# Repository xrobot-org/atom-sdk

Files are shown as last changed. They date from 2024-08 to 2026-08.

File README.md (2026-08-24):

# ATOM-IMU 模块 V5.3

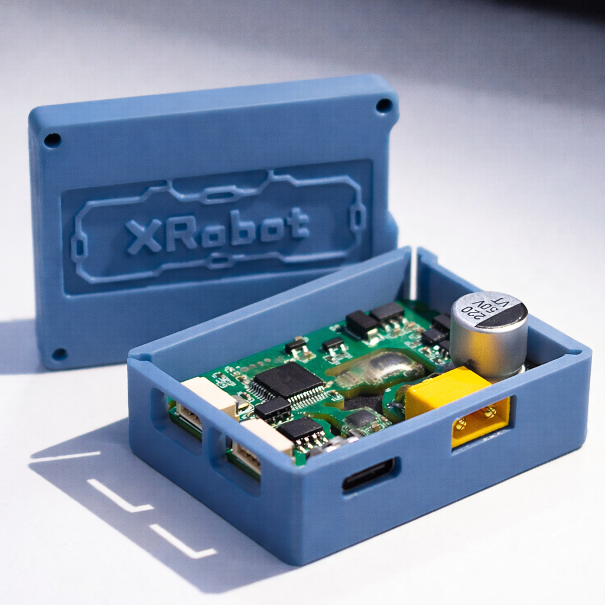
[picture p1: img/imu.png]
imu


## **参数**

- **输出频率**：2-2000Hz
- **支持电压**：5V/24V
- **接口**：USB / UART / CAN
- **支持数据类型**：加速度计 (ACC) / 陀螺仪 (GYRO) / 欧拉角 (EULR) / 四元数 (QUAT)
- **UART 波特率**：2M (数据)
- **CAN 波特率**：1M
- **陀螺仪**：最大量程 ±2000DPS
- **加速度计**：最大量程 ±24G

usb接口会在电脑上枚举出两个CDC虚拟串口，分别为命令行与数据输出。虚拟串口输出的IMU数据与硬件串口格式相同。

不建议使用USB转TTL连接硬件串口。硬件串口波特率较高，需要选择支持此波特率（2M）的USB转TTL模块。模块自带的USB接口延迟更低，速度更快。

## **Yaw轴零漂测试**

零偏通常在10°/h以下，校准环境较好时可达3°/h以下。

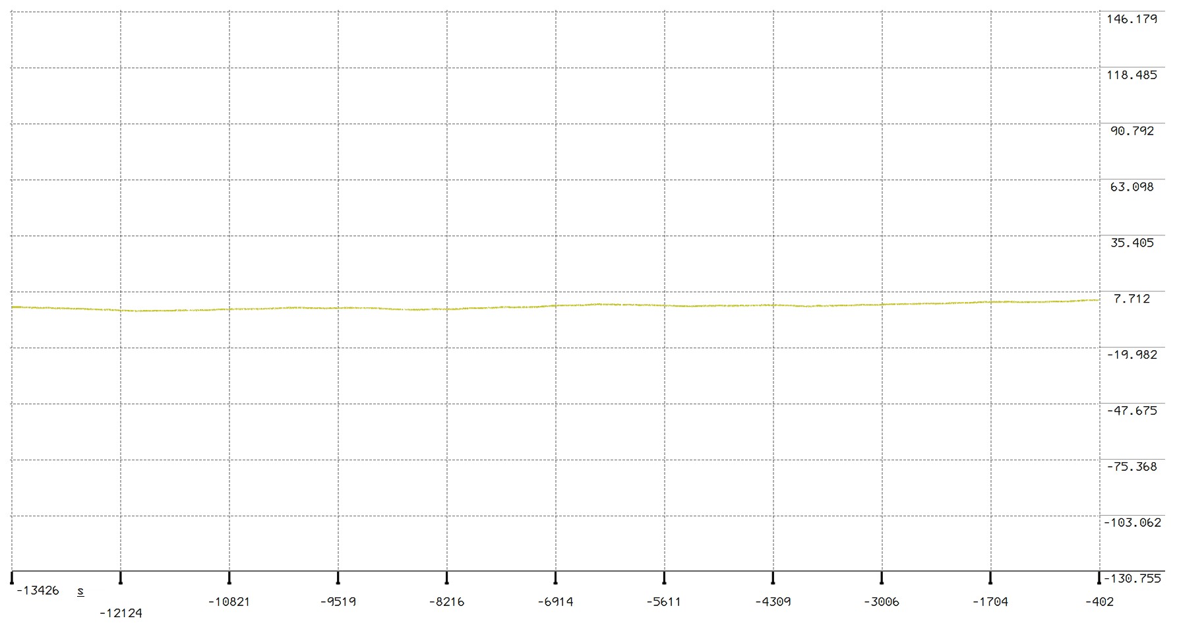
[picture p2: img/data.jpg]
data


## **连接方式**

- **USB**：`UART1(数据输出) UART2(命令行)`
- **UART GH1.25 4P**：
  - `1: SYNC / FSYNC`（可配置为输入或输出）
  - `2: TX`
  - `3: GND`
  - `4: +5V_IN`
- **CAN GH1.25 4P**：
  - `1: CANL`
  - `2: CANH`
  - `3: GND`
  - `4: +5V_IN`
- **XT30 供电**：`24V_IN`

## **示例代码**

```shell
├── linux_uart_example      `Linux UART 解析示例`
├── ros_imu_publisher       `ROS IMU 发布节点`
├── ros_imu_subscriber      `ROS IMU 订阅节点`
├── ros_rviz_example.rviz   `ROS RViz 可视化`
└── stm32_can_example       `STM32 CAN 解析示例（5.3不支持CANFD）`
```

### **Linux UART 示例**

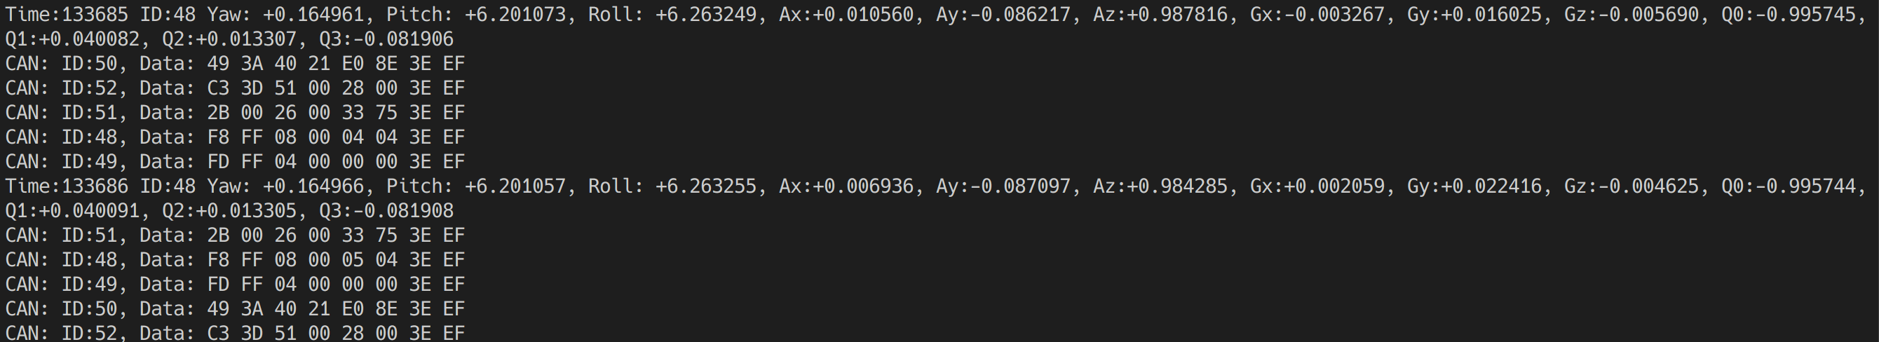
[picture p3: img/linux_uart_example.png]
linux_uart_example


编译并运行示例：

```shell
gcc main.c -o main
./main
```

### **ROS 示例**

VERSION=`rolling`

#### 发布

```shell
colcon build
source install/setup.zsh
ros2 run imu_publisher node_imu
```

#### 订阅

```shell
colcon build
source install/setup.zsh
ros2 run imu_subscriber node_imu
```

### **RViz 可视化**

使用 `ros_rviz_example.rviz` 在 RViz2 中打开。

### **STM32 CAN 示例**

```shell
make
```

## **终端交互**

使用 `picocom`、`putty`、`MobaXTerm` 等工具进行交互，连接USB枚举出的第二个串口设备即可。
示例操作：

```shell
linux@XRobot:~$ ls /dev/ttyACM*
/dev/ttyACM0  /dev/ttyACM1

linux@XRobot:~$ picocom /dev/ttyACM1
```

回车后示例输出：

```shell
XRobot:/$
```

## **IMU 设置**

```shell
# 输入set_imu命令并回车
XRobot:/$ set_imu
# 这一行显示IMU CAN输出的状态，CAN/UART输出同时只能有一个开启
can output disabled.
# 这一行显示IMU 串口输出的状态
uart output enabled.
# 这一行表示帧同步信号FSYNC的模式：
#   0=不启用
#   1=检测上升沿
#   2=检测下降沿
#   3=同时检测上升沿/下降沿
#   4=输出FSYNC时钟（UART口 SYNC/FSYNC 引脚输出）
# 第二个数字代表最近一次FSYNC事件的时间（微秒）
# 第三个数字代表最近一次IMU数据时间戳（微秒）
FSYNC:4 6685000 6690413
# 当 fsync=4（输出）时，会额外显示输出分频参数（Div）
Div:10
# 这一行显示两次反馈数据的时间间隔，单位500us
feedback delay:1
# 这一行显示IMU数据帧的ID
id:48

Usage:
        set_delay  [time]  设置发送延时 1=500us
        set_div    [div]   设置clk_out(FSYNC)分频
        set_can_id [id]    设置can id
        just_float         设置vofa+ just_float输出
        # accl/gyro/quat/eulr只对can模式发送有效
        enable/disable     [accl/gyro/quat/eulr/can/uart]
        fsync              [0: disable 1: rise 2: fall 3: both 4: output]           设置fsync模式
```

## **校准（Calibration）**

完整校准过程约需 **20 分钟**，过程中需要保证 IMU 稳定，每次更改IMU方向后需要等待1分钟以上来使角度稳定。校准的每一步都无顺序要求，可以多次尝试。

```shell
# 上电后等待十分钟，IMU预热
XRobot:/$ imu1 show 600000 1000
# IMU平放，LOGO面朝上
XRobot:/$ imu1 cali
...
# 校准误差绝对值在0.00003以下视为校准成功，理想情况下应当小于0.000015
Calibration error -0.000013
Calibration data saved.
# 更改方向，USB接口面朝下
XRobot:/$ imu1 cali
...
# 侧放IMU，使GH1.25接口朝上
XRobot:/$ imu1 cali
...
# 再次将IMU平放，LOGO面朝上
XRobot:/$ imu2 cali
...
# 搜索得到当地的经纬度，可在谷歌地图中直接右键复制。例如格拉斯哥的经纬度为：55.87241068336635 -4.290120205979219
XRobot:/$ ahrs set_location 55.87 -4.29
Done.
# 校准完成
```

## **测量零漂**

仅作参考，以实际情况为准

```shell
XRobot:/$ ahrs test
Please keep the device steady, start measurement
Please wait
Zero offset:-0.035189°/min
```

## **VOFA+ 可视化数据**

请添加以下自定义命令，使用VOFA+可视化数据。
数据分别为：`w x y z pitch roll yaw`

```shell
ahrs print_quat 1000000 10\r\n
```

## **调整恒温温度**

```shell
# 设置恒温温度  
# 两个IMU温度同步，修改一个即可
XRobot:/$ imu1 set_temp 45

# 重新上电并校准
```

## **FSYNC 输入模式（fsync=1/2/3）**

根据触发模式的不同，`Data.sync`会记录输入信号的边沿触发时间。

## **FSYNC 输出模式（fsync=4）**

当 `fsync` 设置为 `4` 时，模块会在 **UART GH1.25 的 1 号脚（SYNC/FSYNC）** 输出方波时钟，用于外部同步。

- `Data.sync` 字段记录**最近一次 FSYNC 输出上升沿所对应的 IMU 采样结束/数据就绪时间戳**（微秒）
- `Data.sync` 仅在 FSYNC 上升沿发生时更新，其余数据帧会保持为“最近一次上升沿对应的 `sync` 值”
- FSYNC 输出上升沿相对 `Data.sync` 的延迟约为 **8.5µs**（典型值）
- 输出分频由 `set_div [div]` 控制（仅 `fsync=4` 时生效）
- `set_delay [delay]` 为发送/反馈节拍，单位 500µs（`delay=1` 即 500µs）
- 在当前固件中，内部数字滤波带来的群延迟典型值约为 **1.5ms**

输出周期计算：
- **翻转间隔**：`500µs × delay × div`
- **方波周期**：`500µs × delay × div × 2`

示例：`delay=2`（1ms），`div=5`  
方波周期 = `500µs × 2 × 5 × 2 = 10ms`，即 **100Hz**。

---

## **路径延迟**

在当前配置下，IMU 采样周期约为 **500µs**。  
IMU 采样结束到 FSYNC 输出**上升沿**需要约 **8.5µs**。

例如使用 FSYNC 触发相机采集时：

- IMU 采样时间中点约为：`Data.sync - 250µs`
- 相机采集时间中点约为：`Data.sync + 8.5µs + 相机触发上升沿延迟 + 曝光时间/2`

因此可结合 `Data.sync` 与 `Data.time`，在 IMU 数据流中选择**距离相机采集时间中点最近**的 IMU 数据帧。

此外，更改 `set_delay [delay]` 或 `set_div [div]` 均会在**当前周期结束后**生效，运行时更改不会导致相位偏移。  
因此可通过调整 `div`，并同时监控**相机帧时间差**与**IMU 数据时间差**（相对上一帧的 Δt）来对齐相机与 IMU 数据。

sync

## 3D 模型

[Top Model](./3D/Top.step)

[Bottom Model](./3D/Bottom.step)

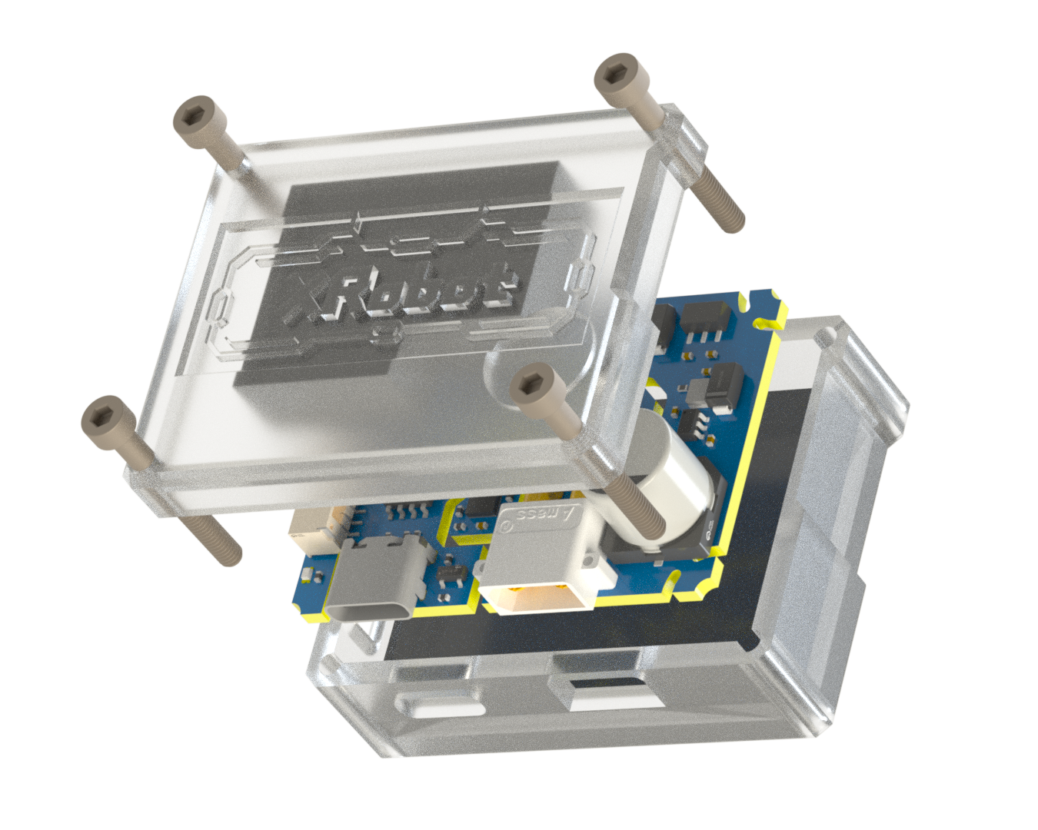
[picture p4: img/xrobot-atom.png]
View


## **传输协议**

### **UART 协议**

- 数据帧包括：前缀，微秒时间戳（time），同步时间戳（sync），四元数，角速度，加速度，欧拉角，CRC8 校验。

```c++
typedef struct __attribute__((packed)) {
  float x;
  float y;
  float z;
} Vector3;

typedef struct __attribute__((packed)) {
  float q0;
  float q1;
  float q2;
  float q3;
} Quaternion;

typedef struct __attribute__((packed)) {
  float yaw;
  float pit;
  float rol;
} EulerAngles;

typedef struct __attribute__((packed))
{
  uint8_t prefix;
  uint64_t time : 40;
  uint64_t sync : 40;
  Quaternion quat_;
  Vector3 gyro_;
  Vector3 accl_;
  EulerAngles eulr_;
  uint8_t crc8;
} Data;
```

### **CAN 协议**

```c++
#define ENCODER_21_MAX_INT ((1u << 21) - 1)
#define CAN_PACK_ID_ACCL 0
#define CAN_PACK_ID_GYRO 1
#define CAN_PACK_ID_EULR 3
#define CAN_PACK_ID_QUAT 4

typedef union {
  struct __attribute__((packed)) {
    int32_t data1 : 21;
    int32_t data2 : 21;
    int32_t data3 : 21;
    int32_t res : 1;
  };
  struct __attribute__((packed)) {
    uint32_t data1_unsigned : 21;
    uint32_t data2_unsigned : 21;
    uint32_t data3_unsigned : 21;
    uint32_t res_unsigned : 1;
  };
  uint8_t raw[8];
} CanData3;

typedef struct __attribute__((packed)) {
  union {
    int16_t data[4];
    uint16_t data_unsigned[4];
  };
} CanData4;

typedef struct {
  struct {
    float x, y, z;
  } accl;
  struct {
    float x, y, z;
  } gyro;
  struct {
    float pitch, roll, yaw;
  } eulr;
  struct {
    float w, x, y, z;
  } quat;
  uint64_t timestamp;
  uint64_t sync_time;
} ImuData;

ImuData imu_data;

static float DecodeFloat21(uint32_t encoded, float min, float max) {
  float norm =
      (float)(encoded & ENCODER_21_MAX_INT) / (float)ENCODER_21_MAX_INT;
  return min + norm * (max - min);
}

static float DecodeInt16Normalized(int16_t value) {
  return (float)value / (float)INT16_MAX;
}

static void ProcessClassicCanPacket(uint32_t id, uint8_t *data) {
  uint32_t packet_type = id - IMU_DEVICE_ID;

  switch (packet_type) {
  case CAN_PACK_ID_ACCL: {
    /* Accelerometer data: ±24g range */
    CanData3 *can_data = (CanData3 *)data;
    imu_data.accl.x = DecodeFloat21(can_data->data1_unsigned, -24.0f, 24.0f);
    imu_data.accl.y = DecodeFloat21(can_data->data2_unsigned, -24.0f, 24.0f);
    imu_data.accl.z = DecodeFloat21(can_data->data3_unsigned, -24.0f, 24.0f);
    break;
  }

  case CAN_PACK_ID_GYRO: {
    /* Gyroscope data: ±2000 deg/s converted to rad/s */
    CanData3 *can_data = (CanData3 *)data;
    float min_gyro = -2000.0f * M_PI / 180.0f;
    float max_gyro = 2000.0f * M_PI / 180.0f;
    imu_data.gyro.x =
        DecodeFloat21(can_data->data1_unsigned, min_gyro, max_gyro);
    imu_data.gyro.y =
        DecodeFloat21(can_data->data2_unsigned, min_gyro, max_gyro);
    imu_data.gyro.z =
        DecodeFloat21(can_data->data3_unsigned, min_gyro, max_gyro);
    break;
  }

  case CAN_PACK_ID_EULR: {
    /* Euler angles: ±π rad */
    CanData3 *can_data = (CanData3 *)data;
    imu_data.eulr.pitch = DecodeFloat21(can_data->data1_unsigned, -M_PI, M_PI);
    imu_data.eulr.roll = DecodeFloat21(can_data->data2_unsigned, -M_PI, M_PI);
    imu_data.eulr.yaw = DecodeFloat21(can_data->data3_unsigned, -M_PI, M_PI);
    break;
  }

  case CAN_PACK_ID_QUAT: {
    /* Quaternion data: normalized int16 */
    CanData4 *can_data = (CanData4 *)data;
    imu_data.quat.w = DecodeInt16Normalized(can_data->data[0]);
    imu_data.quat.x = DecodeInt16Normalized(can_data->data[1]);
    imu_data.quat.y = DecodeInt16Normalized(can_data->data[2]);
    imu_data.quat.z = DecodeInt16Normalized(can_data->data[3]);
    break;
  }

  default:
    /* Unknown packet type */
    break;
  }
}
```

## **固件说明**

- `bootloader.bin`
  - Bootloader 镜像，仅用于写入 Bootloader
- `firmware/` 目录下的 `firmware_*.elf`
  - 应用固件，用于通过 WebDFU 下载到设备
  - 例如：
    - `firmware_25-12-21.elf`
    - `firmware_25-12-28.elf`

请勿将 `bootloader.bin` 作为应用固件下载，否则设备将停留在 Bootloader / DFU 模式。

## **首次烧录流程**

用于首次装配后的上电，或设备中尚无应用固件时。

1. 写入 Bootloader。
   - 使用 1.25 4P 探针连接 SWD 接口，烧录 [bootloader.bin](./firmware/bootloader.bin)
   - 或按硬件流程短接 `boot`（`R66`），进入 DFU 下载模式后烧录 Bootloader
2. 重启设备。
3. 若设备中尚无应用固件，重启后会自动进入 Bootloader。
4. 重新插拔 USB。
5. 打开此网站：[ATOM-IMU 固件更新](https://jiu-xiao.github.io/webdfu/dfu-util/)
6. 选择 `firmware/` 目录下的 `firmware_*.elf` 作为应用固件。
7. 按页面提示完成下载。
8. 再次重新插拔 USB。
9. 命令串口回车后出现 `XRobot:/$`，表示应用固件已启动。

## **应用固件更新**

用于设备已具备可运行的应用固件，需要升级版本时。

1. 准备新的 `firmware_*.elf`。
2. 通过命令串口执行：

   ```sh
   power bl
   ```

3. 设备进入 Bootloader 后，重新插拔 USB。
4. 打开此网站：[ATOM-IMU 固件更新](https://jiu-xiao.github.io/webdfu/dfu-util/)
5. 选择新的 `firmware_*.elf`，按页面提示完成更新。
6. 再次重新插拔 USB。
7. 命令串口回车后出现 `XRobot:/$`，表示更新完成。

若当前应用固件无法进入命令串口，可按“首次烧录流程”重新进入 Bootloader，再重新下载应用固件。

## **焊接建议**

- `BMI088`、`BMI270` 可先对引脚和焊盘植锡，再整体吹焊；可按类似 `BGA` 的回流焊法操作。
- 若多次重焊 `BMI088`、`BMI270` 后仍无法恢复，再排查 `STM32` 侧焊接、`SPI`、`CS`、中断、供电或芯片本体损坏。

## **常见问题与故障处理**

下面的时间戳、文件行号会随固件版本变化，排查时优先看**日志关键字**。

| 现象 / 日志特征 | 最可能原因 | 处理建议 |
| --- | --- | --- |
| 上电后始终停在 Bootloader，或设备行为一直像 DFU 更新设备 | 将 `bootloader.bin` 当成了应用固件烧录 | `bootloader.bin` 仅用于 Bootloader，本体固件请使用 `firmware/` 目录中的 app 固件；重新进入 Bootloader 后，按上面的固件更新流程重新烧录 app |
| 烧录 `bootloader.bin` 后，或短接 `boot`（`R66`）后，USB 仍不枚举 | 通常不是应用固件问题，应优先视为 `USB` 硬件链路异常 | 检查 `USB` 连接器、`USB` 相关电阻、`STM32 USB` 引脚、`USB` 相关晶振及其周边焊点 |
| 两个 COM 口都能枚举，但 IMU 没有正常输出 / 陀螺仪不出数据 | 通常不是 USB 枚举问题，而是 IMU 相关焊接问题 | 优先检查 `BMI088`、`BMI270` 及其周边焊接；如果串口和 CLI 正常，但传感器数据异常，先不要把问题归到上位机 |
| `W [200933] (./Modules/BMI270/BMI270.hpp:398) IMU2:Writesingle timeout reg=0x7E data=0xB6` | `BMI270` 寄存器写入后读回不一致，常见原因为 SPI 虚焊、连焊或芯片本体异常 | 重点检查 `BMI270` 供电、SPI 焊点和芯片姿态；建议补锡后热风重焊，必要时更换芯片 |
| `W [201044] (./Modules/BMI270/BMI270.hpp:341) IMU2:bad CHIP ID` | `BMI270` 软复位后再次读取 `CHIP_ID` 失败，常见原因为 SPI 虚焊 | 优先按 `BMI270` SPI 焊接问题处理；先查焊点、再查芯片 |
| `E [112547] (./Modules/BMI088/BMI088.hpp:260) IMU1: Init failed.` | `BMI088` 初始化失败。源码里对应的是加速度计或陀螺仪 `CHIP_ID` 读取不正确，常见原因为 SPI 虚焊，也可能是供电 / 片选异常 | 重点检查 `BMI088` 本体焊接、SPI 引脚、CS 连接与供电连通；建议先植锡再回流重焊 |
| `W [28734] (./Modules/BMI088/BMI088.hpp:368) IMU1 wait timeout.` | `BMI088` 初始化后 50ms 内未等到新数据中断，常见原因为中断引脚虚焊 | 这类问题常见于 **能读到器件但等不到中断**；优先检查 `BMI088` 中断脚及其到 MCU 的走线/焊点 |
| `BMI088`、`BMI270` 多次重焊后仍无法通信，或 IMU 仍无法识别 | 除传感器本体外，也可能是 `STM32` 侧虚焊 | 检查 `STM32` 与 IMU 相连的 `SPI`、`CS`、中断、供电等相关焊点 |
| 加热电阻不工作，或温度长时间无法上升 | 可能是加热回路异常，也可能是 `STM32 PWM` 引脚虚焊 | 检查加热电阻、供电回路及 `STM32 PWM` 输出相关焊点 |

附上：[XRobot 开源 IMU 手动焊接烈士榜](https://github.com/xrobot-org/atom-sdk/blob/master/XRobot%20%E5%BC%80%E6%BA%90%20IMU%20%E6%89%8B%E5%8A%A8%E7%84%8A%E6%8E%A5%E7%83%88%E5%A3%AB%E6%A6%9C.pdf) 包含最近交流群内的焊接成功/失败记录

## **相关资源**

- [Bilibili 视频演示](https://www.bilibili.com/video/BV1iespeLE5S/?share_source=copy_web)

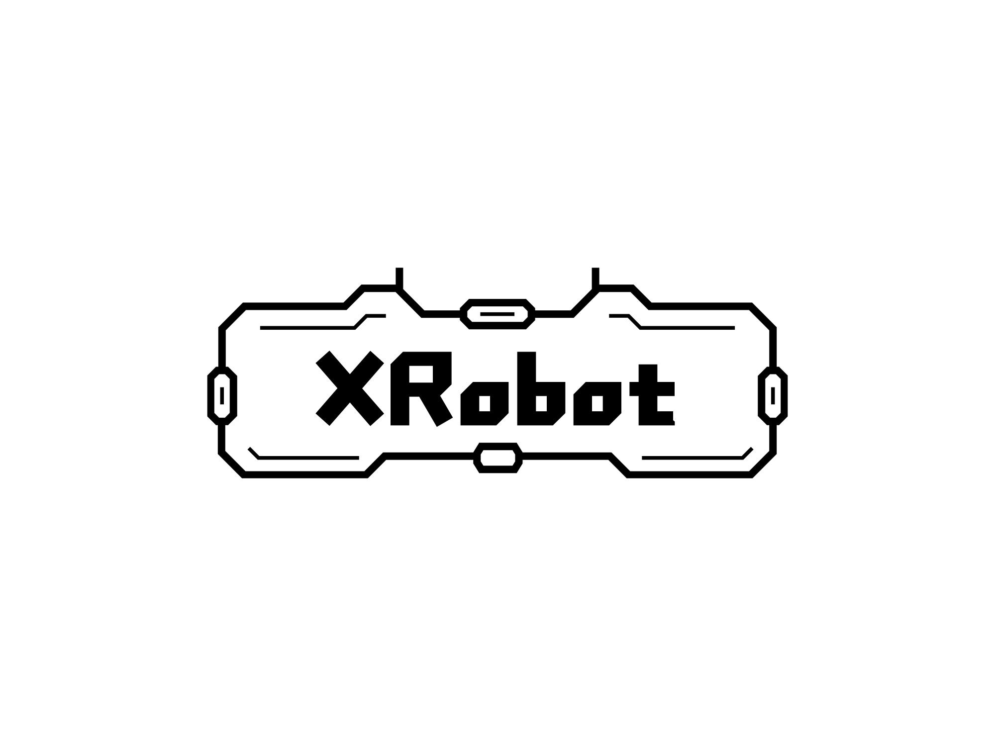
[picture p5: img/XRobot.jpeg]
XRobot


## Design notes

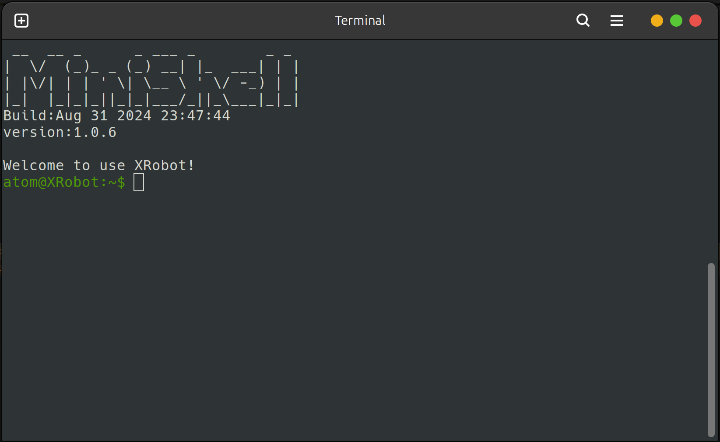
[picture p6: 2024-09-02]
img/terminal.png

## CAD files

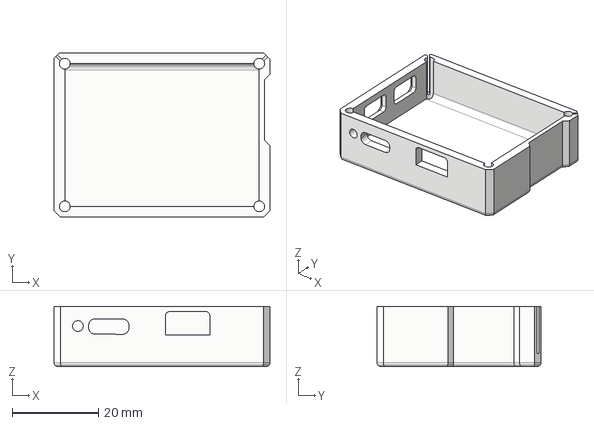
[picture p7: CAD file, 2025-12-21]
3D/Bottom.step
50.1 x 38.1 x 14.0 mm

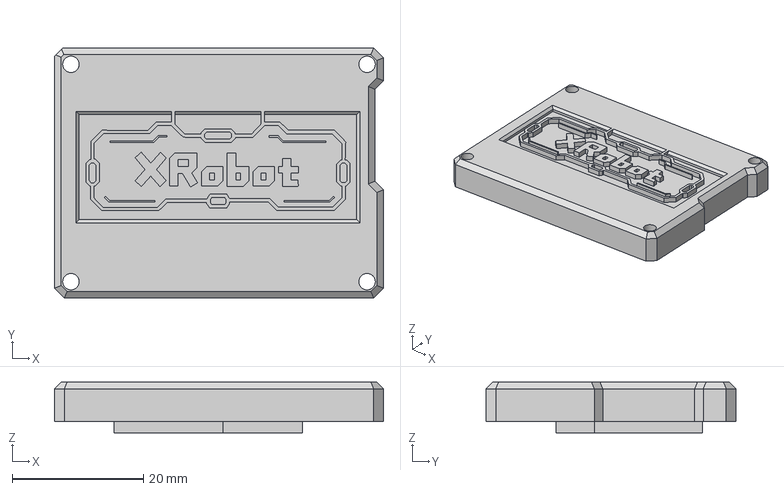
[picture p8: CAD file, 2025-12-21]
3D/Top.step
50.1 x 38.1 x 7.70 mm

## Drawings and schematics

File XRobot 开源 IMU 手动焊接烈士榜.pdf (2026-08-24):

# XRobot 开源 IMU 手动焊接烈士榜

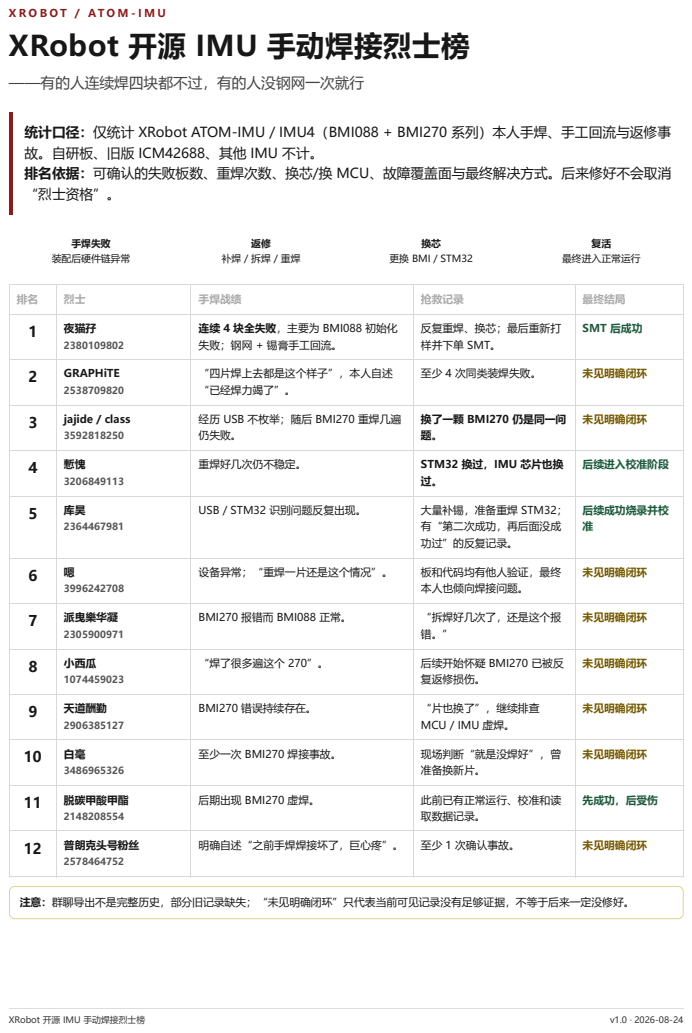
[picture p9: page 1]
——有的人连续焊四块都不过，有的人没钢网一次就行; 手焊失败 装配后硬件链异常; 换芯 更换 BMI / STM32; 复活 最终进入正常运行; XRobot 开源 IMU 手动焊接烈士榜

统计口径：仅统计 XRobot ATOM-IMU / IMU4（BMI088 + BMI270 系列）本人手焊、手工回流与返修事
故。自研板、旧版 ICM42688、其他 IMU 不计。
排名依据：可确认的失败板数、重焊次数、换芯/换 MCU、故障覆盖面与最终解决方式。后来修好不会取消
“烈士资格”。

排名 | 烈士 | 手焊战绩 | 抢救记录 | 最终结局

1 夜猫孖 | 2380109802 | 连续 4 块全失败，主要为 BMI088 初始化 失败；钢网 + 锡膏手工回流。 | 反复重焊、换芯；最后重新打 样并下单 SMT。 | SMT 后成功

2 | GRAPHiTE 2538709820 | “四片焊上去都是这个样子”，本人自述 “已经焊力竭了”。 | 至少 4 次同类装焊失败。 | 未见明确闭环

3 | jajide / class 3592818250 | 经历 USB 不枚举；随后 BMI270 重焊几遍 仍失败。 | 换了一颗 BMI270 仍是同一问 题。 | 未见明确闭环

4 慙愧 | 3206849113 | 重焊好几次仍不稳定。 | STM32 换过，IMU 芯片也换 过。 | 后续进入校准阶段

5 库昊 | 2364467981 | USB / STM32 识别问题反复出现。 | 大量补锡，准备重焊 STM32； 有“第二次成功，再后面没成 功过”的反复记录。 | 后续成功烧录并校 准

6 嗯 | 3996242708 | 设备异常；“重焊一片还是这个情况”。 | 板和代码均有他人验证，最终 本人也倾向焊接问题。 | 未见明确闭环

7 派曳樂华凝 | 2305900971 | BMI270 报错而 BMI088 正常。 | “拆焊好几次了，还是这个报 错。” | 未见明确闭环

8 小西瓜 | 1074459023 | “焊了很多遍这个 270”。 | 后续开始怀疑 BMI270 已被反 复返修损伤。 | 未见明确闭环

9 天道酬勤 | 2906385127 | BMI270 错误持续存在。 | “片也换了”，继续排查 MCU / IMU 虚焊。 | 未见明确闭环

10 白毫 | 3486965326 | 至少一次 BMI270 焊接事故。 | 现场判断“就是没焊好”，曾 准备换新片。 | 未见明确闭环

11 脱碳甲酸甲酯 | 2148208554 | 后期出现 BMI270 虚焊。 | 此前已有正常运行、校准和读 取数据记录。 | 先成功，后受伤

12 普朗克头号粉丝 | 2578464752 | 明确自述“之前手焊焊接坏了，巨心疼”。 | 至少 1 次确认事故。 | 未见明确闭环

注意：群聊导出不是完整历史，部分旧记录缺失；“未见明确闭环”只代表当前可见记录没有足够证据，不等于后来一定没修好。

## 前三名烈士事迹

### 第 1 名 · 夜猫孖 ——《四板全灭，SMT 一键超度》

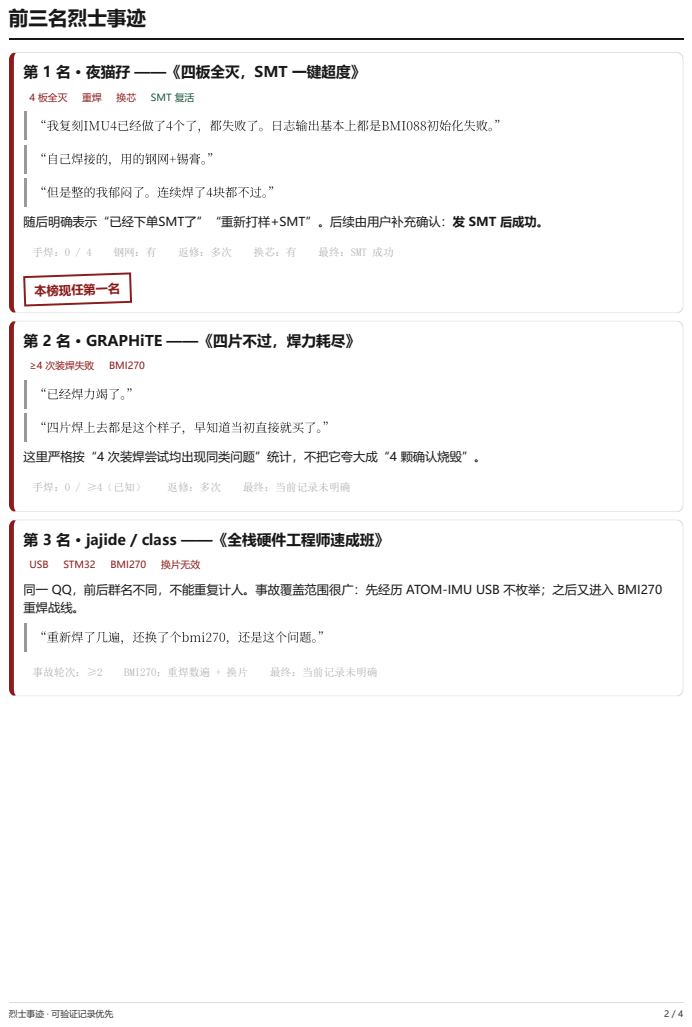
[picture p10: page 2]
“我复刻IMU4已经做了4个了，都失败了。日志输出基本上都是BMI088初始化失败。”; ≥4 次装焊失败 BMI270; “已经焊力竭了。”; “重新焊了几遍，还换了个bmi270，还是这个问题。”; 本榜现任第一名; 烈士事迹 · 可验证记录优先

4 板全灭 重焊 换芯 SMT 复活

“自己焊接的，用的钢网+锡膏。”

“但是整的我郁闷了。连续焊了4块都不过。”
随后明确表示“已经下单SMT了”“重新打样+SMT”。后续由用户补充确认：发 SMT 后成功。

手焊：0 / 4　　钢网：有　　返修：多次　　换芯：有　　最终：SMT 成功

第 2 名 · GRAPHiTE ——《四片不过，焊力耗尽》

“四片焊上去都是这个样子，早知道当初直接就买了。”
这里严格按“4 次装焊尝试均出现同类问题”统计，不把它夸大成“4 颗确认烧毁”。

手焊：0 / ≥4（已知）　　返修：多次　　最终：当前记录未明确

第 3 名 · jajide / class ——《全栈硬件工程师速成班》

USB STM32 BMI270 换片无效
同一 QQ，前后群名不同，不能重复计人。事故覆盖范围很广：先经历 ATOM-IMU USB 不枚举；之后又进入 BMI270
重焊战线。

事故轮次：≥2　　BMI270：重焊数遍 + 换片　　最终：当前记录未明确

## 抢救成功、未结案与特别编制

### 抢救成功榜

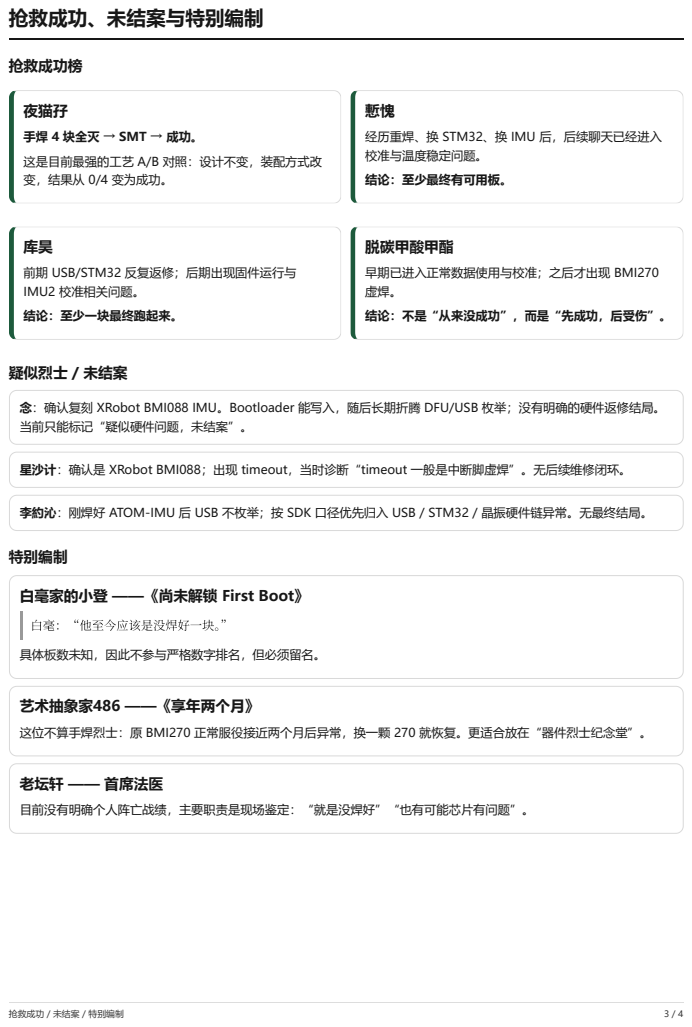
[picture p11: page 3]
疑似烈士 / 未结案; 特别编制; 抢救成功 / 未结案 / 特别编制

夜猫孖
手焊 4 块全灭 → SMT → 成功。
这是目前最强的工艺 A/B 对照：设计不变，装配方式改
变，结果从 0/4 变为成功。

经历重焊、换 STM32、换 IMU 后，后续聊天已经进入
校准与温度稳定问题。
结论：至少最终有可用板。

前期 USB/STM32 反复返修；后期出现固件运行与
IMU2 校准相关问题。
结论：至少一块最终跑起来。

脱碳甲酸甲酯
早期已进入正常数据使用与校准；之后才出现 BMI270
结论：不是“从来没成功”，而是“先成功，后受伤”。

念：确认复刻 XRobot BMI088 IMU。Bootloader 能写入，随后长期折腾 DFU/USB 枚举；没有明确的硬件返修结局。
当前只能标记“疑似硬件问题，未结案”。

星沙计：确认是 XRobot BMI088；出现 timeout，当时诊断“timeout 一般是中断脚虚焊”。无后续维修闭环。

李約沁：刚焊好 ATOM-IMU 后 USB 不枚举；按 SDK 口径优先归入 USB / STM32 / 晶振硬件链异常。无最终结局。

白毫家的小登 ——《尚未解锁 First Boot》

白毫：“他至今应该是没焊好一块。”
具体板数未知，因此不参与严格数字排名，但必须留名。

艺术抽象家486 ——《享年两个月》
这位不算手焊烈士：原 BMI270 正常服役接近两个月后异常，换一颗 270 就恢复。更适合放在“器件烈士纪念堂”。

老坛轩 —— 首席法医
目前没有明确个人阵亡战绩，主要职责是现场鉴定：“就是没焊好”“也有可能芯片有问题”。

## 一次过者，禁止发言

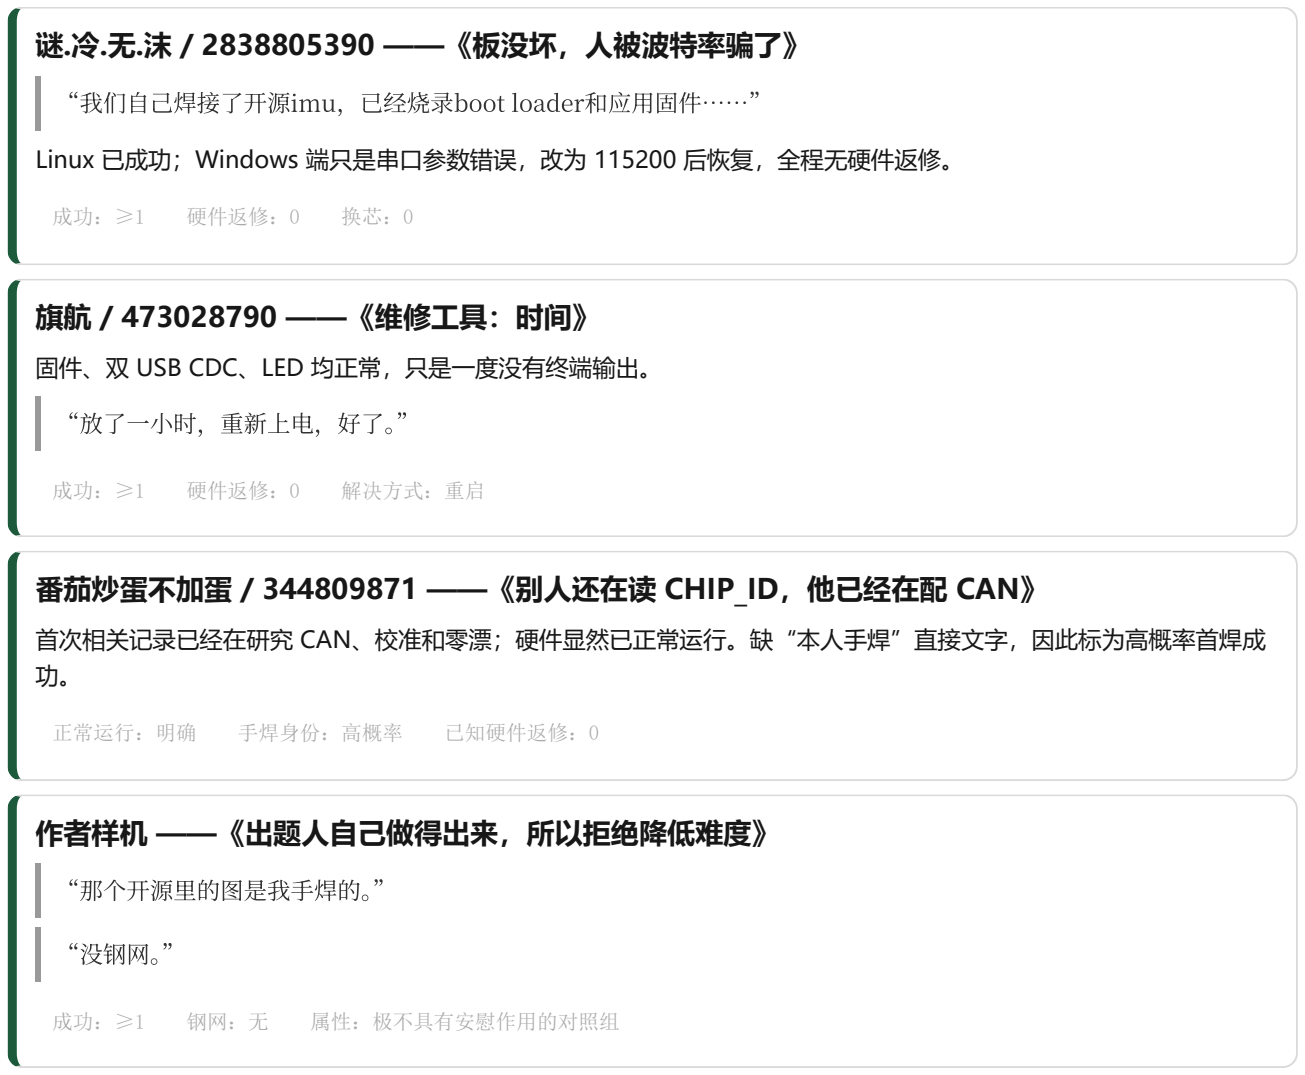
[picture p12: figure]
谜.冷.无.沫 / 2838805390 ——《板没坏，人被波特率骗了》; “我们自己焊接了开源imu，已经烧录boot loader和应用固件……”; Linux 已成功；Windows 端只是串口参数错误，改为 115200 后恢复，全程无硬件返修。; 成功：≥1 硬件返修：0 换芯：0; 旗航 / 473028790 ——《维修工具：时间》; 固件、双 USB CDC、LED 均正常，只是一度没有终端输出。; “放了一小时，重新上电，好了。”; 成功：≥1 硬件返修：0 解决方式：重启; 首次相关记录已经在研究 CAN、校准和零漂；硬件显然已正常运行。缺“本人手焊”直接文字，因此标为高概率首焊成 功。; 正常运行：明确 手焊身份：高概率 已知硬件返修：0; 作者样机 ——《出题人自己做得出来，所以拒绝降低难度》; “那个开源里的图是我手焊的。”; “没钢网。”; 成功：≥1 钢网：无 属性：极不具有安慰作用的对照组

### 番茄炒蛋不加蛋 / 344809871 ——《别人还在读 CHIP_ID，他已经在配 CAN》

### SDK 对应的“验尸关键词”

BMI270 Writesingle timeout / bad CHIP ID：优先查 BMI270 SPI、焊接、供电与芯片本体。 BMI088 Init failed：优先查 BMI088 CHIP_ID 链、SPI、CS 与供电。
BMI088 wait timeout：器件可能已经能通信，但未收到数据中断，优先查 INT 引脚。 Bootloader 已写入但 USB 仍不枚举：优先查 USB 连接器、电阻、STM32 USB 引脚、晶振及周边焊点。 IMU 多次重焊仍不通：不要只盯 BMI，本体之外还应继续检查 STM32 侧 SPI / CS / INT / 供电。

## 当前最高纪录：夜猫孖，手焊连续 4 块全灭；最终 SMT 成功。

本榜最有效维修方案：当手焊返修已经进入无限循环时，停止证明自己，发 SMT。

依据：XRobot 交流群导出、atom-sdk README 与人工补充。导出存在历史缺口，本榜为目前可证实版本。

一次过者 / SDK 验尸关键词 | 4 / 4

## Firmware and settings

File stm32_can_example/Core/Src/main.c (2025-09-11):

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
/* Includes ------------------------------------------------------------------*/
#include "main.h"

/* USER CODE BEGIN Includes */
#include <math.h>
#include <string.h>

/* USER CODE END Includes */

/* USER CODE BEGIN PD */
#define IMU_DEVICE_ID (0x30)

#define M_PI 3.14159265358979323846
#define M_2PI 6.28318530717958647692

/* CAN Packet IDs */
#define CAN_PACK_ID_ACCL 0
#define CAN_PACK_ID_GYRO 1
#define CAN_PACK_ID_EULR 3
#define CAN_PACK_ID_QUAT 4

/* Encoder constants */
#define ENCODER_21_MAX_INT ((1u << 21) - 1)
/* USER CODE END PD */

FDCAN_HandleTypeDef hfdcan1;

UART_HandleTypeDef huart1;
DMA_HandleTypeDef hdma_usart1_rx;
DMA_HandleTypeDef hdma_usart1_tx;

/* USER CODE BEGIN PV */
typedef struct {
  FDCAN_RxHeaderTypeDef header;
  uint8_t data[64];
} can_raw_rx_t;

/* CANFD Data Structure - matches C++ DataCanfd struct */
typedef struct __attribute__((packed)) {
  uint64_t time : 48;
  uint64_t sync : 48;
  float quat[4]; /* w, x, y, z */
  float gyro[3]; /* x, y, z */
  float accl[3]; /* x, y, z */
  float eulr[3]; /* pitch, roll, yaw */
} CanfdData;

/* CAN Classic Data Structures */
typedef union {
  struct __attribute__((packed)) {
    int32_t data1 : 21;
    int32_t data2 : 21;
    int32_t data3 : 21;
    int32_t res : 1;
  };
  struct __attribute__((packed)) {
    uint32_t data1_unsigned : 21;
    uint32_t data2_unsigned : 21;
    uint32_t data3_unsigned : 21;
    uint32_t res_unsigned : 1;
  };
  uint8_t raw[8];
} CanData3;

typedef struct __attribute__((packed)) {
  union {
    int16_t data[4];
    uint16_t data_unsigned[4];
  };
} CanData4;

/* Decoded IMU Data */
typedef struct {
  struct {
    float x, y, z;
  } accl;
  struct {
    float x, y, z;
  } gyro;
  struct {
    float pitch, roll, yaw;
  } eulr;
  struct {
    float w, x, y, z;
  } quat;
  uint64_t timestamp;
  uint64_t sync_time;
} ImuData;

can_raw_rx_t rx_buff;
ImuData imu_data;
uint32_t pack_count = 0;

/* USER CODE END PV */

void SystemClock_Config(void);
static void MX_USART1_UART_Init(void);
/* USER CODE BEGIN PFP */
static float DecodeFloat21(uint32_t encoded, float min, float max);
static float DecodeInt16Normalized(int16_t value);
/* USER CODE END PFP */

/* USER CODE BEGIN 0 */
static const uint8_t CRC8_TAB[256] = {
    0x00, 0x5e, 0xbc, 0xe2, 0x61, 0x3f, 0xdd, 0x83, 0xc2, 0x9c, 0x7e, 0x20,
    0xa3, 0xfd, 0x1f, 0x41, 0x9d, 0xc3, 0x21, 0x7f, 0xfc, 0xa2, 0x40, 0x1e,
    0x5f, 0x01, 0xe3, 0xbd, 0x3e, 0x60, 0x82, 0xdc, 0x23, 0x7d, 0x9f, 0xc1,
    0x42, 0x1c, 0xfe, 0xa0, 0xe1, 0xbf, 0x5d, 0x03, 0x80, 0xde, 0x3c, 0x62,
    0xbe, 0xe0, 0x02, 0x5c, 0xdf, 0x81, 0x63, 0x3d, 0x7c, 0x22, 0xc0, 0x9e,
    0x1d, 0x43, 0xa1, 0xff, 0x46, 0x18, 0xfa, 0xa4, 0x27, 0x79, 0x9b, 0xc5,
    0x84, 0xda, 0x38, 0x66, 0xe5, 0xbb, 0x59, 0x07, 0xdb, 0x85, 0x67, 0x39,
    0xba, 0xe4, 0x06, 0x58, 0x19, 0x47, 0xa5, 0xfb, 0x78, 0x26, 0xc4, 0x9a,
    0x65, 0x3b, 0xd9, 0x87, 0x04, 0x5a, 0xb8, 0xe6, 0xa7, 0xf9, 0x1b, 0x45,
    0xc6, 0x98, 0x7a, 0x24, 0xf8, 0xa6, 0x44, 0x1a, 0x99, 0xc7, 0x25, 0x7b,
    0x3a, 0x64, 0x86, 0xd8, 0x5b, 0x05, 0xe7, 0xb9, 0x8c, 0xd2, 0x30, 0x6e,
    0xed, 0xb3, 0x51, 0x0f, 0x4e, 0x10, 0xf2, 0xac, 0x2f, 0x71, 0x93, 0xcd,
    0x11, 0x4f, 0xad, 0xf3, 0x70, 0x2e, 0xcc, 0x92, 0xd3, 0x8d, 0x6f, 0x31,
    0xb2, 0xec, 0x0e, 0x50, 0xaf, 0xf1, 0x13, 0x4d, 0xce, 0x90, 0x72, 0x2c,
    0x6d, 0x33, 0xd1, 0x8f, 0x0c, 0x52, 0xb0, 0xee, 0x32, 0x6c, 0x8e, 0xd0,
    0x53, 0x0d, 0xef, 0xb1, 0xf0, 0xae, 0x4c, 0x12, 0x91, 0xcf, 0x2d, 0x73,
    0xca, 0x94, 0x76, 0x28, 0xab, 0xf5, 0x17, 0x49, 0x08, 0x56, 0xb4, 0xea,
    0x69, 0x37, 0xd5, 0x8b, 0x57, 0x09, 0xeb, 0xb5, 0x36, 0x68, 0x8a, 0xd4,
    0x95, 0xcb, 0x29, 0x77, 0xf4, 0xaa, 0x48, 0x16, 0xe9, 0xb7, 0x55, 0x0b,
    0x88, 0xd6, 0x34, 0x6a, 0x2b, 0x75, 0x97, 0xc9, 0x4a, 0x14, 0xf6, 0xa8,
    0x74, 0x2a, 0xc8, 0x96, 0x15, 0x4b, 0xa9, 0xf7, 0xb6, 0xe8, 0x0a, 0x54,
    0xd7, 0x89, 0x6b, 0x35};

/**
 * @brief Calculate CRC8
 * 
 * @param buf Data buffer
 * @param len Data length
 * @param crc Initial CRC
 * @return uint8_t Calculated CRC
 */
uint8_t CalculateCRC8(const uint8_t *buf, size_t len, uint8_t crc) {
  while (len-- > 0) {
    crc = CRC8_TAB[(crc ^ *buf++) & 0xff];
  }
  return crc;
}

/**
 * @brief Decode 21-bit unsigned integer to float
 * @param encoded 21-bit encoded value
 * @param min Minimum float value
 * @param max Maximum float value
 * @return Decoded float value
 */
static float DecodeFloat21(uint32_t encoded, float min, float max) {
  float norm =
      (float)(encoded & ENCODER_21_MAX_INT) / (float)ENCODER_21_MAX_INT;
  return min + norm * (max - min);
}

/**
 * @brief Decode int16 normalized value to float (for quaternion)
 * @param value int16 value
 * @return Normalized float [-1, 1]
 */
static float DecodeInt16Normalized(int16_t value) {
  return (float)value / (float)INT16_MAX;
}

/**
 * @brief Process CAN-FD packet
 */
static void ProcessCanfdPacket(uint8_t *data) {
  CanfdData *canfd_data = (CanfdData *)data;

  imu_data.timestamp = canfd_data->time;
  imu_data.sync_time = canfd_data->sync;

  /* Quaternion */
  imu_data.quat.w = canfd_data->quat[0];
  imu_data.quat.x = canfd_data->quat[1];
  imu_data.quat.y = canfd_data->quat[2];
  imu_data.quat.z = canfd_data->quat[3];

  /* Gyroscope */
  imu_data.gyro.x = canfd_data->gyro[0];
  imu_data.gyro.y = canfd_data->gyro[1];
  imu_data.gyro.z = canfd_data->gyro[2];

  /* Accelerometer */
  imu_data.accl.x = canfd_data->accl[0];
  imu_data.accl.y = canfd_data->accl[1];
  imu_data.accl.z = canfd_data->accl[2];

  /* Euler angles */
  imu_data.eulr.pitch = canfd_data->eulr[0];
  imu_data.eulr.roll = canfd_data->eulr[1];
  imu_data.eulr.yaw = canfd_data->eulr[2];
}

/**
 * @brief Process Classic CAN packet
 */
static void ProcessClassicCanPacket(uint32_t id, uint8_t *data) {
  uint32_t packet_type = id - IMU_DEVICE_ID;

  switch (packet_type) {
  case CAN_PACK_ID_ACCL: {
    /* Accelerometer data: ±24g range */
    CanData3 *can_data = (CanData3 *)data;
    imu_data.accl.x = DecodeFloat21(can_data->data1_unsigned, -24.0f, 24.0f);
    imu_data.accl.y = DecodeFloat21(can_data->data2_unsigned, -24.0f, 24.0f);
    imu_data.accl.z = DecodeFloat21(can_data->data3_unsigned, -24.0f, 24.0f);
    break;
  }

  case CAN_PACK_ID_GYRO: {
    /* Gyroscope data: ±2000 deg/s converted to rad/s */
    CanData3 *can_data = (CanData3 *)data;
    float min_gyro = -2000.0f * M_PI / 180.0f;
    float max_gyro = 2000.0f * M_PI / 180.0f;
    imu_data.gyro.x =
        DecodeFloat21(can_data->data1_unsigned, min_gyro, max_gyro);
    imu_data.gyro.y =
        DecodeFloat21(can_data->data2_unsigned, min_gyro, max_gyro);
    imu_data.gyro.z =
        DecodeFloat21(can_data->data3_unsigned, min_gyro, max_gyro);
    break;
  }

  case CAN_PACK_ID_EULR: {
    /* Euler angles: ±π rad */
    CanData3 *can_data = (CanData3 *)data;
    imu_data.eulr.pitch = DecodeFloat21(can_data->data1_unsigned, -M_PI, M_PI);
    imu_data.eulr.roll = DecodeFloat21(can_data->data2_unsigned, -M_PI, M_PI);
    imu_data.eulr.yaw = DecodeFloat21(can_data->data3_unsigned, -M_PI, M_PI);
    break;
  }

  case CAN_PACK_ID_QUAT: {
    /* Quaternion data: normalized int16 */
    CanData4 *can_data = (CanData4 *)data;
    imu_data.quat.w = DecodeInt16Normalized(can_data->data[0]);
    imu_data.quat.x = DecodeInt16Normalized(can_data->data[1]);
    imu_data.quat.y = DecodeInt16Normalized(can_data->data[2]);
    imu_data.quat.z = DecodeInt16Normalized(can_data->data[3]);
    break;
  }

  default:
    /* Unknown packet type */
    break;
  }
}

void HAL_FDCAN_RxFifo0Callback(FDCAN_HandleTypeDef *hcan, uint32_t RxFifo0ITs) {
  (void)RxFifo0ITs;
  while (HAL_FDCAN_GetRxMessage(hcan, FDCAN_RX_FIFO0, &rx_buff.header,
                                rx_buff.data) == HAL_OK) {
    pack_count++;

    if (rx_buff.header.FDFormat == FDCAN_FD_CAN) {
      /* CAN-FD packet */
      if (rx_buff.header.Identifier == IMU_DEVICE_ID &&
          rx_buff.header.DataLength == FDCAN_DLC_BYTES_64) {
        ProcessCanfdPacket(rx_buff.data);
      }
    } else {
      /* Classic CAN packet */
      ProcessClassicCanPacket(rx_buff.header.Identifier, rx_buff.data);
    }
  }
}
/* USER CODE END 0 */

/**
  * @brief  The application entry point.
  * @retval int
  */
int main(void)
{

  /* MCU Configuration--------------------------------------------------------*/

  /* Reset of all peripherals, Initializes the Flash interface and the Systick. */
  HAL_Init();

  /* Configure the system clock */
  SystemClock_Config();

  /* Initialize all configured peripherals */
  MX_GPIO_Init();
  MX_DMA_Init();
  MX_FDCAN1_Init();
  MX_USART1_UART_Init();
  /* USER CODE BEGIN 2 */
  FDCAN_FilterTypeDef can_filter = {0};

  /* Configure standard ID filter */
  can_filter.IdType = FDCAN_STANDARD_ID;
  can_filter.FilterIndex = 0;
  can_filter.FilterType = FDCAN_FILTER_MASK;
  can_filter.FilterConfig = FDCAN_FILTER_TO_RXFIFO0;
  can_filter.FilterID1 = 0x0000;
  can_filter.FilterID2 = 0x0000;
  if (HAL_FDCAN_ConfigFilter(&hfdcan1, &can_filter) != HAL_OK) {
    Error_Handler();
  }

  /* Configure extended ID filter */
  can_filter.IdType = FDCAN_EXTENDED_ID;
  can_filter.FilterIndex = 1;
  can_filter.FilterType = FDCAN_FILTER_MASK;
  can_filter.FilterConfig = FDCAN_FILTER_TO_RXFIFO0;
  can_filter.FilterID1 = 0x0000;
  can_filter.FilterID2 = 0x0000;
  if (HAL_FDCAN_ConfigFilter(&hfdcan1, &can_filter) != HAL_OK) {
    Error_Handler();
  }

  /* Start FDCAN */
  HAL_FDCAN_Start(&hfdcan1);
  HAL_FDCAN_ActivateNotification(&hfdcan1, FDCAN_IT_RX_FIFO0_NEW_MESSAGE, 0);

  /* Initialize IMU data structure */
  memset(&imu_data, 0, sizeof(imu_data));
  imu_data.quat.w = 1.0f; /* Initialize quaternion to identity */

  /* USER CODE END 2 */

  /* Infinite loop */
  /* USER CODE BEGIN WHILE */
  while (1) {
    HAL_GPIO_TogglePin(GPIOB, GPIO_PIN_0);

    /* 在这里可以使用解析后的IMU数据 */
    /* Use decoded IMU data here */
    /*
     * imu_data.gyro.x/y/z - 陀螺仪数据 (rad/s)
     * imu_data.accl.x/y/z - 加速度计数据 (g)
     * imu_data.quat.w/x/y/z - 四元数
     * imu_data.eulr.pitch/roll/yaw - 欧拉角 (rad)
     * imu_data.timestamp - 时间戳
     * imu_data.sync_time - 同步时间
     */

    HAL_Delay(100);
    /* USER CODE END WHILE */

    /* USER CODE BEGIN 3 */
  }
  /* USER CODE END 3 */
}

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
/**
  * @brief  Period elapsed callback in non blocking mode
  * @note   This function is called  when TIM15 interrupt took place, inside
  * HAL_TIM_IRQHandler(). It makes a direct call to HAL_IncTick() to increment
  * a global variable "uwTick" used as application time base.
  * @param  htim : TIM handle
  * @retval None
  */
void HAL_TIM_PeriodElapsedCallback(TIM_HandleTypeDef *htim)
{
  if (htim->Instance == TIM15)
  {
    HAL_IncTick();
  }
}

/**
  * @brief  This function is executed in case of error occurrence.
  * @retval None
  */
void Error_Handler(void)
{
  /* USER CODE BEGIN Error_Handler_Debug */
  /* User can add his own implementation to report the HAL error return state */
  __disable_irq();
  while (1) {
  }
  /* USER CODE END Error_Handler_Debug */
}
#ifdef USE_FULL_ASSERT
/**
  * @brief  Reports the name of the source file and the source line number
  *         where the assert_param error has occurred.
  * @param  file: pointer to the source file name
  * @param  line: assert_param error line source number
  * @retval None
  */
void assert_failed(uint8_t *file, uint32_t line)
{
  /* USER CODE BEGIN 6 */
  /* User can add his own implementation to report the file name and line
     number, ex: printf("Wrong parameters value: file %s on line %d\r\n", file,
     line) */
  /* USER CODE END 6 */
}
#endif /* USE_FULL_ASSERT */

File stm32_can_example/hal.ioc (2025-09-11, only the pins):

Mcu.UserName=STM32G431KBUx
PA10.Signal=USART1_RX
PA11.Signal=FDCAN1_RX
PA12.Signal=FDCAN1_TX
PA13.Signal=SYS_JTMS-SWDIO
PA14.Signal=SYS_JTCK-SWCLK
PA9.Signal=USART1_TX
PB0.GPIO_Label=LED_RUN
PB0.Signal=GPIO_Output

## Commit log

2024-08-30 add stm32_can_example
2024-08-31 Use wch driver.
2024-09-01 Update 3D Model
    [bottom.STEP, top.STEP]
2025-03-02 Update calibration.
2025-09-05 Update stm32_can_example
2025-09-05 fix: 修正 EulerAngles 顺序与数据打印格式
    [main.c]
2025-09-05 ros_imu_publisher: 增加 IMU 本地时间同步及 ROS 时间戳对齐优化
2025-09-11 Update 3D module
    [imu_bottom.step, imu_top.step]
2025-09-16 更新 README.md
2026-04-26 docs: tighten soldering guidance
2026-04-26 docs: trim soldering notes
2026-08-24 Add soldering records link to README
    Added a link to the XRobot open-source IMU soldering success/failure records.

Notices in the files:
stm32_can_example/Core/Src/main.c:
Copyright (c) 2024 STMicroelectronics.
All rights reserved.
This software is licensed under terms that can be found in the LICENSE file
